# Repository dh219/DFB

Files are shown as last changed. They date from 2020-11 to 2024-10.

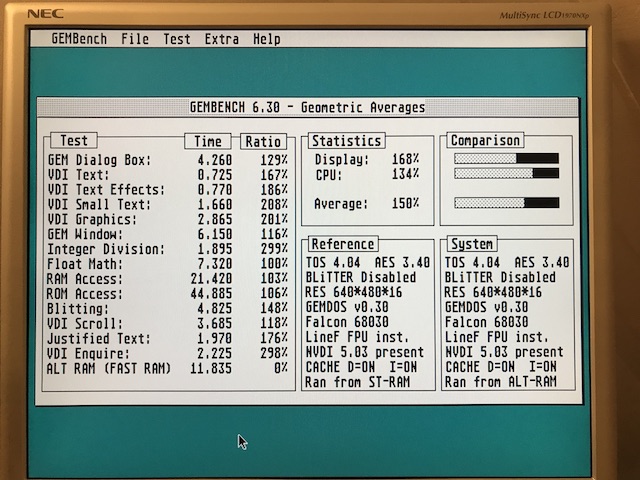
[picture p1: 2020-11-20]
wiki_resources/rev2b_performance.jpeg

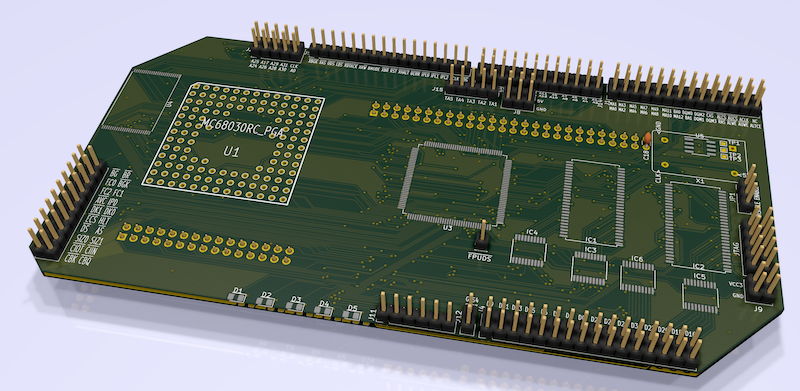
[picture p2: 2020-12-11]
wiki_resources/rev3_kicad.png

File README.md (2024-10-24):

## David's Falcon Booster (DFB)

#### An attempt to build a low-cost memory expansion and accelerator board for the Atari Falcon.

The primary goals of the project are to:

* Be a plug-in board requiring no soldering on the Falcon;
* Increase available RAM beyond the 14MB the stock Falcon can be expanded to;
* Be low cost;
* Provide some acceleration;
* Allow the PSU to remain in the case;
* Be open source.

Some development narration on this project is provided in the [Wiki](https://github.com/dh219/DFB/wiki).

Firmware source (ISE), board design files (KiCAD) and any source for support programs are published at each release.

#### Capabilities

As of 2024 the published firmware supports 64 (2x32) or 128 (2x64) MB of TT-RAM.

It supports only a PGA128 MC68030. The board has been tested between 32 and 50MHz with the CPU normally being the limiting factor.

The FPU is optional and can be run at half the CPU speed, or with an independent oscillator. This is configured by a resistor placement choice.

The Falcon's on-board FPU, if fitted, should be removed to prevent bus conflicts.

---

*Copyright 2020-24 D Henderson, released under GPL2.0*

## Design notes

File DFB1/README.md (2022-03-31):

## David's Falcon Booster Mark 1 (DFB1)

#### Hardware

The directory *kicad5* contains all the Kicad 5 project files and libraries necessary to order or edit the DFB1 PCB.

Kicad is an open source EDA suite. https://www.kicad.org/

Premade gerber files may be found in the releases.

#### Firmware

##### Building

The directory *ise* contains the project files, verilog source and hardware definition files needed to build the firmware for the CPLD.

AMD/Xilinx's ISE Design Suite is required to edit and synthesise the CPLD firmware. Tested with ISE Webpack v14.7.

https://www.xilinx.com/products/design-tools/ise-design-suite/ise-webpack.html

Precompiled (JEDEC) firmwares may be found in the releases.

##### Flashing

Flashing the CPLD can be achieved with the free and open source xc3sprog tool and a Xilinx programmer, or a Raspberry Pi.

http://xc3sprog.sourceforge.net/

https://linuxjedi.co.uk/2021/11/25/revisiting-xilinx-jtag-programming-from-a-raspberry-pi/

#### Assembling

Pick and place positioning files and automated bill of materials file are not yet available, but when they are the board house may be able to partially assemble boards for you.

In the meantime, and for hobbiests, a hand assembly video guide is available on my YouTube channel:

https://www.youtube.com/playlist?list=PLZBirr2xVnY4OkgEWdXNjq90gBGzXah9X

#### Software

I recommend Anders Granlund's TFTools suite to enable the TT-RAM on the DFB1 board. FASTRAM.PRG detects and activates the TT-RAM. MAPROM.PRG will additionally copy TOS to TT-RAM for even better performance but may require a cold boot to work completely correctly. BLITFIX.PRG does not, unfortunately, work with the Falcon.

https://github.com/agranlund/tftools

NVDI is recommended to use the stock TOS4 desktop with TT-RAM enabled as there is no way of disabling the Blitter in TOS4 and unfortunately the Blitter is not compatible with TT-RAM. NVDI replaces the VDI calls that use the Blitter.

An excellent alternative to all the above is EmuTOS, but sadly, as of version 1.1.1, it does not support the Falcon's 16-bit true colour mode.

https://emutos.sourceforge.io/

---

*Copyright 2020-21 D Henderson, released under GPL2.0*

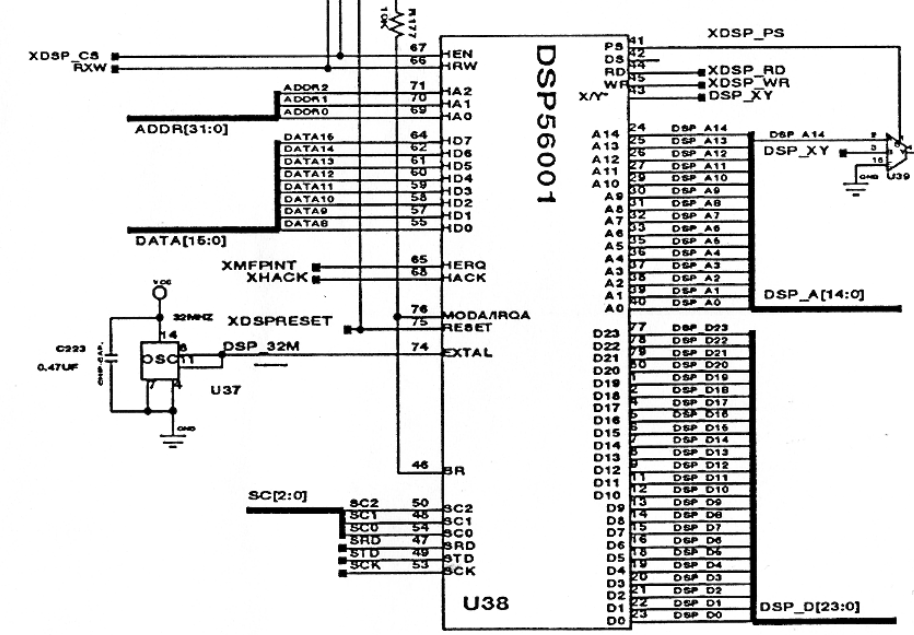
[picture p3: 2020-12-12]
wiki_resources/DSP_schematic.png

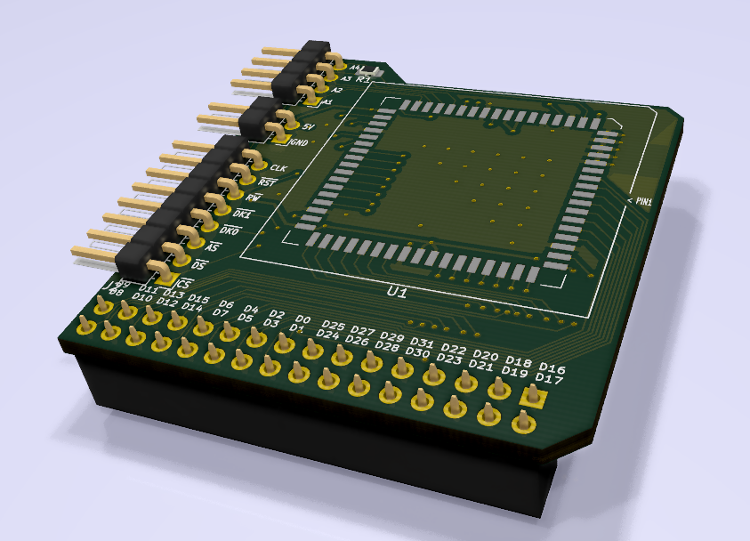
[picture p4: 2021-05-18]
wiki_resources/FPU_hat_render.png

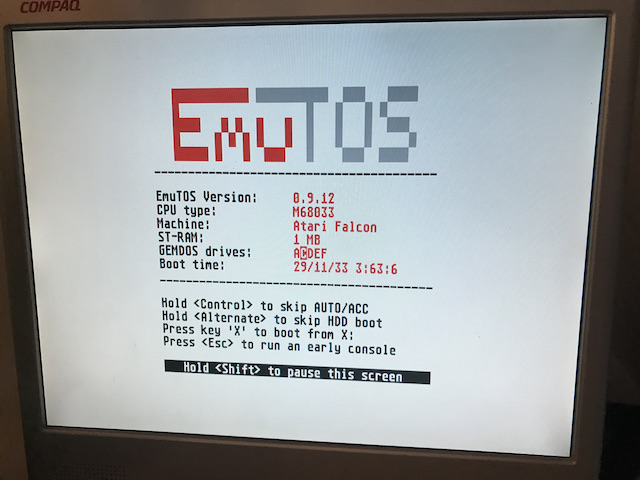
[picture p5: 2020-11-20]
wiki_resources/etos_odd_behaviour.jpeg

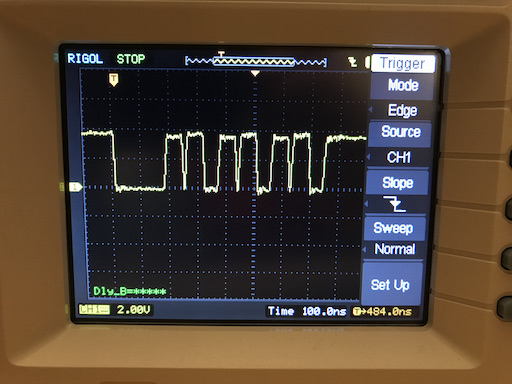
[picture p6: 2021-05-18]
wiki_resources/DSACK0_DFB_timing.jpeg

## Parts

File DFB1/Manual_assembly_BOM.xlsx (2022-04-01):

Assembly Order | Designator | Package | Quantity | Designation | Mouser part | Farnell part | LCSC part | RS part | Approx indiv cost (GBP ex VAT) | Approx line cost | Approximate overall component cost (GBP)
1 | U4 | TQFP-144_20x20mm_P0.5mm | 1 | XC95288XL-10TQG144I |  | 2907289 |  |  | 22 | 22 | NO VAT
1 | C25,C24,C11,C9,C8,C23,C17,C16,C15,C14,C13,C12,C20,C18,C2,C7,C6,C4 | C_0805_2012Metric_Pad1.18x1.45mm_HandSolder | 18 | 100n | Jellybean |  |  |  | 0.03 | 0.54 | 63.04
1 | C22,C10,C19,C1,C3 | C_0805_2012Metric_Pad1.18x1.45mm_HandSolder | 5 | 10u | Jellybean |  |  |  | 0.03 | 0.15
1 | C5 | C_0805_2012Metric_Pad1.18x1.45mm_HandSolder | 1 | 330p | Jellybean |  |  |  | 0.03 | 0.03 | +VAT
1 | R3,R2 | R_0805_2012Metric_Pad1.20x1.40mm_HandSolder | 2 | 2k2 | Jellybean |  |  |  | 0.03 | 0.06 | 75.648
1 | R18,R1,R20,R19,R16 | R_0805_2012Metric_Pad1.20x1.40mm_HandSolder | 5 | 33R NOMINAL | Jellybean |  |  |  | 0.03 | 0.15
1 | RN7,RN6,RN5,RN4,RN2,RN1 | R_Array_Convex_4x0603 | 6 | 10K 1206 |  | 3550050 |  |  | 0.04 | 0.24
1 | R12 | R_0805_2012Metric_Pad1.20x1.40mm_HandSolder | 1 | 4k7 OPTION | Jellybean |  |  |  | 0.03 | 0.03
1 | U1 | SOT-223 | 1 | LM1117-3.3 |  | 3588827 |  |  | 0.65 | 0.65
1 | J9 | PinHeader_1x06_P2.54mm_Vertical | 1 | Conn_01x06_Male | Jellybean |  |  |  | 0.06 | 0.06
TEST JTAG AND PROGRAM |  |  |  |  |  |  |  |  |  | 0
 |  |  |  |  |  |  |  |  |  | 0
2 | X1 | Oscillator_DIP-14-DUAL | 1 | 5V DIP 8 or DIP14 |  | 2508732 |  |  | 3.1 | 3.1
2 | J3 | PinSocket_2x15_P2.54mm_Vertical | 1 | Conn_01x30 |  | 2847247 |  |  | 0.81 | 0.81
2 | J1 | PinSocket_2x25_P2.54mm_Vertical | 1 | Conn_01x50 |  | 2847249 |  |  | 1.35 | 1.35
2 | U2 | MC68030RC_PGA | 1 | MC68030RC_PGA | See Exxos store |  |  |  | 8 | 8
2 | J2 | PinHeader_2x04_P2.54mm_Vertical | 1 | Conn_02x04_Odd_Even | Jellybean |  |  |  | 0.08 | 0.08
TEST IN FALCON SHOULD NOW ACCELERATE |  |  |  |  |  |  |  |  |  | 0
 |  |  |  |  |  |  |  |  |  | 0
3 | IC6,IC5,IC4,IC3 | TSSOP-20_4.4x6.5mm_P0.65mm | 4 | SN74CB3T3245PW |  | 3120942 |  |  | 2.1 | 8.4
3 | IC2,IC1 | TSOP-II-54_22.2x10.16mm_P0.8mm | 2 | IS42S16160G-7TLI |  | 2253829 |  |  | 3.9 | 7.8
TEST IN FALCON SHOULD NOW DETECT TTRAM AND PASS YAARTTT |  |  |  |  |  |  |  |  |  | 0
 |  |  |  |  |  |  |  |  |  | 0
ENTIRELY OPTIONAL TO TASTE |  |  |  |  |  |  |  |  |  | 0
4 | D5,D4,D3,D2,D1 | LED_0805_2012Metric_Pad1.15x1.40mm_HandSolder | 5 | LED SMD 0805 |  | 1581242 |  |  | 0.12 | 0.6
4 | R10,R9,R8,R7,R6 | R_0805_2012Metric_Pad1.20x1.40mm_HandSolder | 5 | 1k | Jellybean |  |  |  | 0.03 | 0.15
 |  |  |  |  |  |  |  |  |  | 0
4 | U3 | PLCC-68_THT-Socket | 1 | MC68882 |  | 1183031 |  |  | 2.15 | 2.15
 |  |  |  |  |  |  |  |  |  | 0
DEBUG/EXPANSION |  |  |  |  |  |  |  |  |  | 0
X | J6 | PinHeader_1x02_P2.54mm_Vertical | 1 | Conn_01x02_Male | Jellybean |  |  |  | 0.02 | 0.02
X | JP1 | PinHeader_1x02_P2.54mm_Vertical | 1 | Conn_01x02_Male | Jellybean |  |  |  | 0.02 | 0.02
X | J5 | PinHeader_2x02_P2.54mm_Vertical | 1 | Conn_02x02_Odd_Even | Jellybean |  |  |  | 0.04 | 0.04
X | J8,J4 | PinHeader_2x03_P2.54mm_Vertical | 2 | Conn_02x03_Odd_Even | Jellybean |  |  |  | 0.06 | 0.12
NOT YET TESTED |  |  |  |  |  |  |  |  |  | 0
E | U5 | TSOP-I-48_18.4x12mm_P0.5mm | 1 | 5V 29F800C-TSOP-48 |  |  |  | 914-2768 | 3.3 | 3.3
 |  |  |  |  |  |  |  |  |  | 0
ONLY FIT IF STABILITY REQUIRES (TEST EACH ONE) |  |  |  |  |  |  |  |  |  | 0
D | R15,R14,R13 | R_0805_2012Metric_Pad1.20x1.40mm_HandSolder | 3 | 10k OPTION | Jellybean |  |  |  | 0.03 | 0.09
 |  |  |  |  |  |  |  |  |  | 0
DO NOT FIT IF R18 POPULATED |  |  |  |  |  |  |  |  |  | 0
O | X2 | Oscillator_DIP-14-DUAL | 1 | 5V DIP 8 or DIP14 |  |  |  |  | 3.1 | 3.1

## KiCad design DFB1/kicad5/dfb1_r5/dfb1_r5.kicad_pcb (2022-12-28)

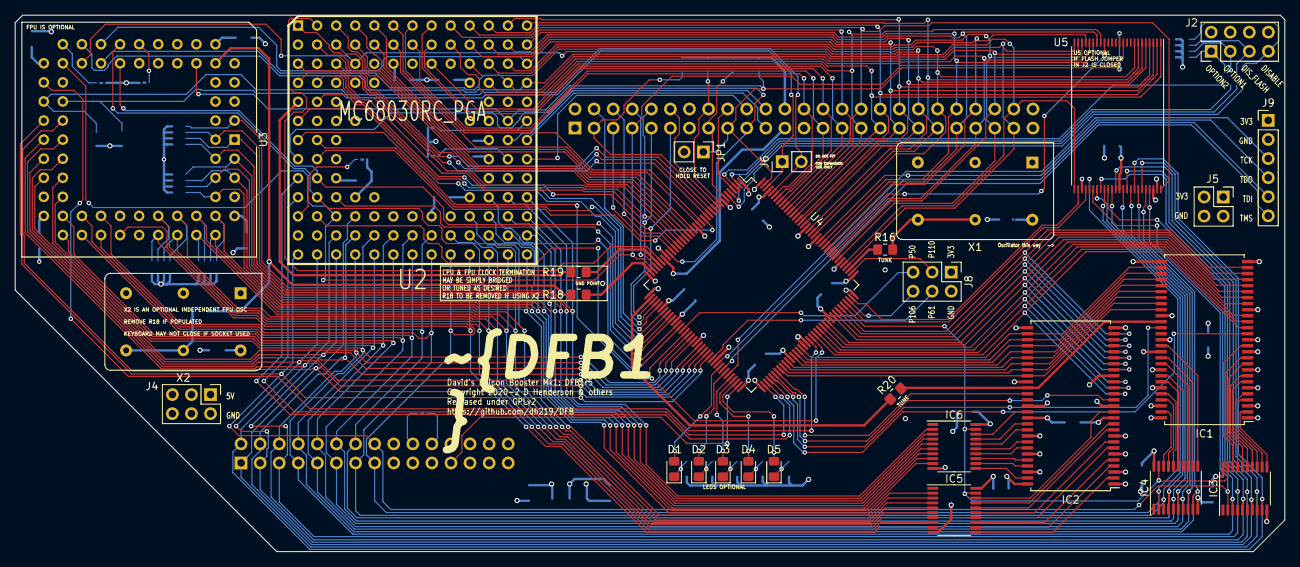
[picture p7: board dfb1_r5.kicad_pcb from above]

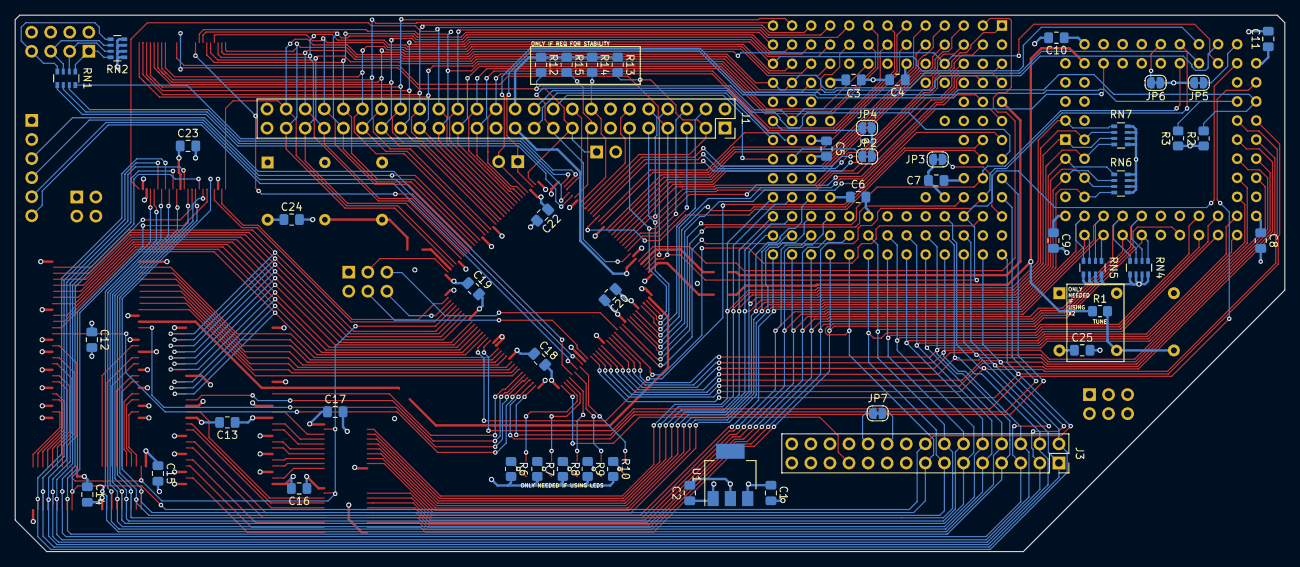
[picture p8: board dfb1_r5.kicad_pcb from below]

Board: 4 copper layers, 169.0 x 71.4 mm, 79 parts (51 on the bottom side), 204 nets.

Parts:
C1, C3, C10, C19, C22: 10u; C_0805_2012Metric_Pad1.18x1.45mm_HandSolder
C2, C4, C6, C7, C8, C9, C11, C12, C13, C14, C15, C16, C17, C18, C20, C23, C24, C25: 100n; C_0805_2012Metric_Pad1.18x1.45mm_HandSolder
C5: 330p; C_0805_2012Metric_Pad1.18x1.45mm_HandSolder
D1, D2, D3, D4, D5: LED; LED_0805_2012Metric_Pad1.15x1.40mm_HandSolder
IC1, IC2: IS42S16320D-7TL; TSOP-II-54_22.2x10.16mm_P0.8mm
IC3, IC4, IC5, IC6: SN74CB3T3245PW; TSSOP-20_4.4x6.5mm_P0.65mm
J1: Conn_01x50; PinSocket_2x25_P2.54mm_Vertical
J2: Conn_02x04_Odd_Even; PinHeader_2x04_P2.54mm_Vertical
J3: Conn_01x30; PinSocket_2x15_P2.54mm_Vertical
J4, J8: Conn_02x03_Odd_Even; PinHeader_2x03_P2.54mm_Vertical
J5: Conn_02x02_Odd_Even; PinHeader_2x02_P2.54mm_Vertical
J6: Conn_01x02_Female; PinHeader_1x02_P2.54mm_Vertical
J9: Conn_01x06_Male; PinHeader_1x06_P2.54mm_Vertical
JP1: Jumper_NO_Small; PinHeader_1x02_P2.54mm_Vertical
JP2, JP3, JP4, JP5, JP6, JP7: Jumper_NC_Small; SolderJumper-2_P1.3mm_Bridged_RoundedPad1.0x1.5mm_DAVID
R1, R16, R18, R19, R20: 33R NOMINAL; R_0805_2012Metric_Pad1.20x1.40mm_HandSolder
R2, R3: 2k2; R_0805_2012Metric_Pad1.20x1.40mm_HandSolder
R6, R7, R8, R9, R10: 1k; R_0805_2012Metric_Pad1.20x1.40mm_HandSolder
R12: 4k7 OPTION; R_0805_2012Metric_Pad1.20x1.40mm_HandSolder
R13, R14, R15: 10k OPTION; R_0805_2012Metric_Pad1.20x1.40mm_HandSolder
RN1, RN2, RN4, RN5, RN6, RN7: 10K; R_Array_Convex_4x0603
U1: LM1117-3.3; SOT-223
U2: MC68030RC_PGA
U3: MC68882; PLCC-68_THT-Socket
U4: XC95288XL-10TQG144I; TQFP-144_20x20mm_P0.5mm
U5: 29F800C-TSOP-48; TSOP-I-48_18.4x12mm_P0.5mm
X1, X2: CXO_DIP14_DIP8_DUAL; Oscillator_DIP-14-DUAL

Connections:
/68030/CDIS: JP2.1, U2.H12
/68030/CIIN: JP3.1, U2.L1
/68030/FPUSIZE: JP6.1, U3.18
/68030/FPU_A0: JP5.1, U3.26
/68030/MMUDIS: JP4.1, U2.F13
/CPLD/LED1: D1.2, U4.64
/CPLD/LED2: D2.2, U4.66
/CPLD/LED3: D3.2, U4.68
/CPLD/LED4: D4.2, U4.69
/CPLD/LED5: D5.2, U4.70
/CPLD/P50: J8.5, U4.50
/CPLD/P61: J8.4, U4.61
/CPLD/P106: J8.6, U4.106
/CPLD/P110: J8.3, U4.110
/CPLD/TCK: J9.3, U4.67
/CPLD/TDI: J9.5, U4.63
/CPLD/TDO: J9.4, U4.122
/CPLD/TMS: J9.6, U4.65
/CPUBGI: J3.22, JP7.2
/CPUBGO: J3.20, JP7.1
/ENABLE_J: J2.7, RN1.4, RN2.5
/EN_ALTRAM_J: J2.3, RN1.2, RN2.7
/EN_FLASH_J: J2.5, RN1.3, RN2.6
/OPTION_J: J2.1, RN1.1, RN2.8
A0: U2.A2, U4.31
A1: J1.48, U2.C4, U3.25, U4.113, U5.25
A2: J1.47, U2.D13, U3.24, U4.112, U5.24
A3: J1.46, U2.D12, U3.23, U4.116, U5.23
A4: J1.45, U2.C13, U3.22, U4.115, U5.22
A5: J1.44, U2.C12, U4.119, U5.21
A6: J1.43, U2.D11, U4.117, U5.20
A7: J1.42, U2.B13, U4.121, U5.19
A8: J1.41, U2.B12, U4.120, U5.18
A9: J1.40, U2.C11, U4.124, U5.8
A10: J1.39, U2.A13, U4.125, U5.7
A11: J1.38, U2.C10, U4.126, U5.6
A12: J1.37, U2.B11, U4.128, U5.5
A13: J1.36, U2.A12, U4.129, U5.4
A14: J1.35, U2.B10, U4.130, U5.3
A15: J1.34, U2.A11, U4.131, U5.2
A16: J1.33, U2.B9, U4.132, U5.1
A17: J1.32, U2.A10, U4.134, U5.48
A18: J1.31, U2.C8, U4.133, U5.17
A19: J1.30, U2.A9, U4.135
A20: J1.29, U2.B8, U4.136
A21: J1.28, U2.A8, U4.137
A22: J1.27, U2.B7, U4.138
A23: J1.26, U2.A7, U4.139
A24: U2.A6, U4.16
A25: U2.B6, U4.17
A26: U2.A5, U4.19
A27: U2.B5, U4.20
A28: U2.A4, U4.21
A29: U2.B4, U4.22
A30: U2.A3, U4.23
A31: U2.B3, U4.24
BA0: IC1.20, IC2.20, U4.96
BA1: IC1.21, IC2.21, U4.97
BMODE: J1.12, U4.10
CLKOSC: R16.1, U4.111
CPUCLK: R19.2, U2.E1
D0: IC6.2, RN7.1, U2.K13, U3.3
D1: IC6.3, RN7.2, U2.K12, U3.2
D2: IC6.4, RN7.3, U2.L13, U3.1
D3: IC6.6, RN7.4, U2.M13, U3.68
D4: IC6.5, RN6.1, U2.L12, U3.67
D5: IC6.7, RN6.3, U2.K11, U3.66
D6: IC6.8, RN6.2, U2.M12, U3.65
D7: IC6.9, RN6.4, U2.L11, U3.64
D8: IC5.2, RN5.4, U2.N13, U3.62
D9: IC5.3, RN5.3, U2.M11, U3.60
D10: IC5.4, RN5.2, U2.L10, U3.59
D11: IC5.5, RN5.1, U2.N12, U3.58
D12: IC5.6, RN4.4, U2.M10, U3.57
D13: IC5.7, RN4.3, U2.N11, U3.56
D14: IC5.8, RN4.2, U2.M9, U3.55
D15: IC5.9, RN4.1, U2.N10, U3.54
D16: IC4.2, J3.15, U2.N9, U3.50, U5.29
D17: IC4.4, J3.14, U2.M8, U3.49, U5.31
D18: IC4.3, J3.13, U2.N8, U3.48, U5.33
D19: IC4.5, J3.12, U2.N7, U3.47, U5.35
D20: IC4.6, J3.11, U2.M7, U3.46, U5.38
D21: IC4.7, J3.10, U2.N6, U3.45, U5.40
D22: IC4.8, J3.9, U2.M6, U3.44, U5.42
D23: IC4.9, J3.8, U2.N5, U3.42, U5.44
D24: IC3.3, J3.7, U2.M5, U3.40, U4.52, U5.30
D25: IC3.5, J3.6, U2.N4, U3.39, U4.53, U5.32
D26: IC3.4, J3.5, U2.N3, U3.38, U4.54, U5.34
D27: IC3.7, J3.4, U2.M4, U3.37, U4.56, U5.36
D28: IC3.6, J3.3, U2.N2, U3.36, U4.57, U5.39
D29: IC3.9, J3.2, U2.M3, U3.35, U4.58, U5.41
D30: IC3.8, J3.1, U2.L4, U3.34, U4.59, U5.43
D31: IC3.2, J3.16, U2.N1, U3.33, U4.60, U5.45
DQM0: IC1.15, U4.76
DQM1: IC1.39, U4.77
DQM2: IC2.15, U4.78
DQM3: IC2.39, U4.79
ENABLE: RN1.5, U4.6
EN_ALTRAM: RN1.7, U4.2
EN_FLASH: RN1.6, U4.5
FC0: J1.11, U2.D2, U4.39
FC1: J1.10, U2.C1, U4.25
FC2: J1.9, U2.D1, U4.40
FPUCLK: R1.1, R18.2, U3.11
GND: C1.2, C2.2, C3.2, C4.2, C5.2, C6.2, C7.2, C8.2, C9.2, C10.2, C11.2, C12.2, C13.2, C14.2, C15.2, C16.2, C17.2, C18.2, C19.2, C20.2, C22.2, C23.2, C24.2, C25.2, IC1.6, IC1.12, IC1.19, IC1.28, IC1.41, IC1.46, IC1.52, IC1.54, IC2.6, IC2.12, IC2.19, IC2.28, IC2.41, IC2.46, IC2.52, IC2.54, IC3.10, IC4.10, IC5.10, IC6.10, J1.1, J1.2, J2.2, J2.4, J2.6, J2.8, J3.17, J3.18, J3.19, J4.2, J4.4, J4.6, J5.2, J5.4, J8.2, J9.2, JP1.2, R6.2, R7.2, R8.2, R9.2, R10.2, U1.1, U2.C5, U2.C7, U2.C9, U2.E3, U2.E11, U2.F3, U2.G3, U2.G11, U2.J3, U2.J11, U2.L5, U2.L7, U2.L8, U2.L9, U3.5, U3.6, U3.7, U3.8, U3.9, U3.12, U3.14, U3.19, U3.30, U3.41, U3.51, U3.63, U4.18, U4.29, U4.36, U4.47, U4.62, U4.72, U4.89, U4.90, U4.99, U4.108, U4.114, U4.123, U4.144, U5.27, U5.46, X1.4, X1.7, X2.4, X2.7
KHZ500: J3.23, U4.71
MA0: IC1.23, IC2.23, U4.100
MA1: IC1.24, IC2.24, U4.101
MA2: IC1.25, IC2.25, U4.102
MA3: IC1.26, IC2.26, U4.103
MA4: IC1.29, IC2.29, U4.88
MA5: IC1.30, IC2.30, U4.87
MA6: IC1.31, IC2.31, U4.86
MA7: IC1.32, IC2.32, U4.85
MA8: IC1.33, IC2.33, U4.83
MA9: IC1.34, IC2.34, U4.82
MA10: IC1.22, IC2.22, U4.98
MA11: IC1.35, IC2.35, U4.81
MA12: IC1.36, IC2.36, U4.80
MD0: IC2.2, IC5.11
MD1: IC2.4, IC5.12
MD2: IC2.5, IC5.13
MD3: IC2.7, IC5.14
MD4: IC2.8, IC5.15
MD5: IC2.10, IC5.16
MD6: IC2.11, IC5.17
MD7: IC2.13, IC5.18
MD8: IC2.42, IC6.18
MD9: IC2.44, IC6.17
MD10: IC2.45, IC6.16
MD11: IC2.47, IC6.15
MD12: IC2.48, IC6.14
MD13: IC2.50, IC6.13
MD14: IC2.51, IC6.12
MD15: IC2.53, IC6.11
MD16: IC1.2, IC3.11
MD17: IC1.4, IC3.12
MD18: IC1.5, IC3.13
MD19: IC1.7, IC3.14
MD20: IC1.8, IC3.15
MD21: IC1.10, IC3.16
MD22: IC1.11, IC3.17
MD23: IC1.13, IC3.18
MD24: IC1.42, IC4.11
MD25: IC1.44, IC4.12
MD26: IC1.45, IC4.13
MD27: IC1.47, IC4.14
MD28: IC1.48, IC4.15
MD29: IC1.50, IC4.16
MD30: IC1.51, IC4.17
MD31: IC1.53, IC4.18
unnamed: D1.1, R10.1
unnamed: D2.1, R9.1
unnamed: D3.1, R8.1
unnamed: D4.1, R7.1
unnamed: D5.1, R6.1
unnamed: R1.2, X2.8, X2.11
unnamed: R16.2, X1.8, X1.11
unnamed: R18.1, U4.35
unnamed: R19.1, U4.32
unnamed: R20.1, U4.38
OPTION: RN1.8, U4.3
RAMCLK: IC1.38, IC2.38, R20.2
ROM_A19: U4.118, U5.16
SIZ0: U2.L2, U4.51
SIZ1: U2.K3, U4.48
VCC: C1.1, C3.1, C4.1, C5.1, C6.1, C7.1, C8.1, C9.1, C10.1, C11.1, C23.1, C24.1, C25.1, J1.24, J1.25, J3.28, J3.29, J3.30, J4.1, J4.3, J4.5, JP2.2, JP3.2, JP4.2, JP5.2, JP6.2, R2.1, R3.1, R12.1, R13.1, R14.1, R15.1, RN4.5, RN4.6, RN4.7, RN4.8, RN5.5, RN5.6, RN5.7, RN5.8, RN6.5, RN6.6, RN6.7, RN6.8, RN7.5, RN7.6, RN7.7, RN7.8, U1.3, U2.C6, U2.D4, U2.D10, U2.F2, U2.F11, U2.H3, U2.H11, U2.K4, U2.K10, U2.L6, U3.10, U3.16, U3.17, U3.27, U3.43, U3.52, U3.53, U3.61, U5.37, U5.47, X1.14, X2.14
VCC3: C2.1, C12.1, C13.1, C14.1, C15.1, C16.1, C17.1, C18.1, C19.1, C20.1, C22.1, IC1.1, IC1.3, IC1.9, IC1.14, IC1.27, IC1.37, IC1.43, IC1.49, IC2.1, IC2.3, IC2.9, IC2.14, IC2.27, IC2.37, IC2.43, IC2.49, IC3.20, IC4.20, IC5.20, IC6.20, J5.1, J5.3, J8.1, J9.1, RN2.1, RN2.2, RN2.3, RN2.4, U1.2, U4.1, U4.8, U4.37, U4.42, U4.55, U4.73, U4.84, U4.109, U4.127, U4.141
XCPUCLK: J1.23, U4.30
XR~W: J1.7, U2.L3, U3.28, U4.34, U5.11
~AS: U2.J2, U3.21, U4.46
~AVEC: U2.E2, U4.43
~BERR: J1.19, U2.H1, U4.28
~BG: U2.B2, U4.12
~BGK: U2.C3, U4.14
~BOE: IC3.19, IC4.19, IC5.19, IC6.19, U4.104
~BR: U2.A1, U4.13
~CAS: IC1.17, IC2.17, U4.94
~CBACK: U2.J1, U4.75
~CBREQ: U2.K1, U4.74
~DS: U2.K2, U3.20, U4.49
~DSACK0: U2.F1, U4.45
~DSACK1: U2.G2, U4.44
~FPUCS: U3.29, U4.91
~FPUDSACK0: J6.2, R2.2, U3.31, U4.140
~FPUDSACK1: J6.1, R3.2, U3.32, U4.142
~HLT: U2.H2, U4.15
~IPL0: J1.20, U2.H13
~IPL1: J1.21, U2.G13
~IPL2: J1.22, U2.G12
~LDS: J1.5, U4.27
~RAMWE: IC1.16, IC2.16, U4.93
~RAS: IC1.18, IC2.18, U4.95
~ROMCE: U4.107, U5.26
~ROMOE: U4.105, U5.28
~RST: J1.17, JP1.1, R12.2, U2.F12, U3.13, U4.143, U5.12
~STERM: U2.G1, U4.92
~UDS: J1.6, U4.26
~XAS: J1.4, U4.41
~XBG: J1.15, R15.2, U4.7
~XBGK: J1.3, R13.2, U4.11
~XBR: J1.16, R14.2, U4.9
~XDTACK: J1.8, U4.33
~XHALT: J1.18, U4.4

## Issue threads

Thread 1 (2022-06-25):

Footprint Tweak

DominoTree, 2022-06-25:
Thank you for the time and effort you've put in to developing something amazing!

I built Gerbers and placed an order for some boards (with PCBWay) and they informed me that the pad-to-pad clearance for the FPGA was 0.02mm below their minimum tolerance for any soldermask color other than green. After checking the Xilinx spec sheet at https://www.xilinx.com/support/documents/package_specs/tq144.pdf it looks like the maximum pin width is 0.27mm, whereas the default KiCad package is 0.30mm.

I made a new package based with 0.27mm pins tweaked the wider track widths connecting to it, as well as made sure the smaller tracks were centered in the pads, and then built new Gerbers and submitted them. Hopefully they pass PCBWay's DRC with those changes. I'll post an update here if so or if I end up needing to do more.

My changes are at https://github.com/DominoTree/DFB if you'd like to swap footprints or anything. I used KiCad 6 and just modified the footprint on the PCB itself - if you want to use it and have trouble let me know and I'll re-generate it in KiCad 5 and save it as its own footprint. This could be a quick way to make these boards easier and cheaper for more folks to have manufactured.

Thanks again, and feel free to let me know if you have any questions or if there's anything I can help with!
Nick

dh219, 2022-07-29:
Hi there.

I'm not ignoring this, but I've not yet decided on what the best course of action is. I'm unsure that changing the pad widths to be exactly the pin widths is a good idea. Currently I'm leaning towards leaving it as it is, as you've provided an alternative already and there is an option at PCBWay, just in the stock colour. I'll continue to mull this over and perhaps seek advice.

Cheers.

DominoTree, 2022-07-30:
No worries - it's certainly nothing critical and it's an issue I'd never
even considered until I ran into it! Makes me curious to find out
whether other fabs doing purple soldermask have similar color-specific
tolerance requirements.

I don't recall coming across an actual design document from Xilinx with
the suggested footprint for the package, but I believe there was still
some "wiggle room" to make the pads slightly larger and still remain
within the fab's requirements, so that might make sense if it works.

The boards and stencil came out great and I just need to get a hold of
some FPGAs to assemble one and confirm it all still works as expected.

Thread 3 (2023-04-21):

Kicad 5 project -- missing custom footprint duplicated from standard footprint

sporniket, 2023-04-21:
Hello,

Working on fixing the portability of the kicad project (see also PR #2 ).

There is a reference to a footprint `Jumper:SolderJumper-2_P1.3mm_Bridged_RoundedPad1.0x1.5mm_DAVID` that seems to me a duplicate from the builtin `Jumper:SolderJumper-2_P1.3mm_Bridged_RoundedPad1.0x1.5mm`, but as it is located in the same system library, it is outside this repository.

What is different in your custom reference ? Is it possible to go back to the standard footprint ? Otherwise, it would be good that you include your custom version into the local footprint library that you made.

dh219, 2023-04-26:
Hi there,

The only difference is that instead of two briding traces that would have to be cut by the intrepid modder, this has only one. It's trivial and it could be swapped back with ease.

Or the jumper could be dropped -- they're their in case switching to 16 bit FPU mode was required after manufacture.

I thought the library ('david') was included, but I'll review this when I get a time. Thanks.

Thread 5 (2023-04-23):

Custom libraries are not referenced in the kicad project

sporniket, 2023-04-23:
When opening the schematics, all the custom symbols are replaced by big squares labelled with "??".

&rArr; either keep the library folder where it is and add the custom symbol libraries into the project, taking care of expressing the pathes relative to the project directory

&rArr; or move the library folder into the kicad project and then add these libraries into the project (in this case Kicad use relative pathes without being told to) &rArr; see PR #2

dh219, 2023-04-26:
Will fold this into [issue 3](https://github.com/dh219/DFB/issues/3)

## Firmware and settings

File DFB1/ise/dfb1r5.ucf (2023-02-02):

NET "A<27>" LOC = "P20" ;
NET "A<28>" LOC = "P21" ;
NET "A<29>" LOC = "P22" ;
NET "A<30>" LOC = "P23" ;
NET "A<31>" LOC = "P24" ;
NET "FC<1>" LOC = "P25" ;
NET "UDS" LOC = "P26" ;
NET "LDS" LOC = "P27" ;

NET "XBR" LOC = "P9" ;
NET "BMODE" LOC = "P10" ;
NET "XBGK" LOC = "P11" ;
NET "BG" LOC = "P12" ;
NET "BR" LOC = "P13" ;
NET "BGK" LOC = "P14" ;
NET "HLT" LOC = "P15" ;
NET "A<24>" LOC = "P16" ;
NET "A<24>" LOC = "P16" ;
NET "A<25>" LOC = "P17" ;
NET "A<26>" LOC = "P19" ;

NET "BERR" LOC = "P28" ;
NET "XCPUCLK" LOC = "P30" ;
NET "A<0>" LOC = "P31" ;
NET "CPUCLK" LOC = "P32" ;
NET "XDTACK" LOC = "P33" ;


NET "OPTION1" LOC = "P2" ;
NET "OPTION2" LOC = "P3" ;
NET "XHALT" LOC = "P4" ;
NET "EN_FLASH" LOC = "P5" ;
NET "ENABLE" LOC = "P6" ;
NET "XBG" LOC = "P7" ;


NET "XRW" LOC = "P34" ;
NET "FPUCLK" LOC = "P35" ;
NET "CLKRAM" LOC = "P38" ;
NET "FC<0>" LOC = "P39" ;
NET "FC<2>" LOC = "P40" ;
NET "XAS" LOC = "P41" ;
NET "AVEC" LOC = "P43" ;
NET "DSACK<1>" LOC = "P44" ;

NET "A<19>" LOC = "P135" ;
NET "A<20>" LOC = "P136" ;
NET "A<21>" LOC = "P137" ;
NET "A<22>" LOC = "P138" ;
NET "A<23>" LOC = "P139" ;
NET "FPUDSACK<0>" LOC = "P140" ;
NET "FPUDSACK<1>" LOC = "P142" ;
NET "RST" LOC = "P143" ;

NET "DSACK<0>" LOC = "P45" ;
NET "AS" LOC = "P46" ;
NET "SIZ<1>" LOC = "P48" ;
NET "DS" LOC = "P49" ;

NET "A<14>" LOC = "P130" ;
NET "A<15>" LOC = "P131" ;
NET "A<16>" LOC = "P132" ;
NET "A<18>" LOC = "P133" ;
NET "A<17>" LOC = "P134" ;

NET "P50" LOC = "P50" ;
NET "SIZ<0>" LOC = "P51" ;
NET "D<0>" LOC = "P52" ;
NET "D<1>" LOC = "P53" ;
NET "D<2>" LOC = "P54" ;
NET "D<3>" LOC = "P56" ;
NET "D<4>" LOC = "P57" ;
NET "D<5>" LOC = "P58" ;
NET "D<6>" LOC = "P59" ;

NET "A<6>" LOC = "P117" ;
NET "ROM_A19" LOC = "P118" ;
NET "A<5>" LOC = "P119" ;
NET "A<8>" LOC = "P120" ;
NET "A<7>" LOC = "P121" ;
NET "A<9>" LOC = "P124" ;
NET "A<10>" LOC = "P125" ;
NET "A<11>" LOC = "P126" ;
NET "A<12>" LOC = "P128" ;
NET "A<13>" LOC = "P129" ;

NET "D<7>" LOC = "P60" ;
NET "P61" LOC = "P61" ;
NET "LED<1>" LOC = "P64" ;
NET "LED<2>" LOC = "P66" ;
NET "LED<3>" LOC = "P68" ;
NET "LED<4>" LOC = "P69" ;
NET "LED<5>" LOC = "P70" ;

NET "P110" LOC = "P110" ;
NET "CLKOSC" LOC = "P111" ;
NET "A<2>" LOC = "P112" ;
NET "A<1>" LOC = "P113" ;
NET "A<4>" LOC = "P115" ;
NET "A<3>" LOC = "P116" ;

NET "KHZ500" LOC = "P71" ;
NET "CBREQ" LOC = "P74" ;
NET "CBACK" LOC = "P75" ;
NET "DQM<0>" LOC = "P76" ;
NET "DQM<1>" LOC = "P77" ;
NET "DQM<2>" LOC = "P78" ;

NET "MA<0>" LOC = "P100" ;
NET "MA<1>" LOC = "P101" ;
NET "MA<2>" LOC = "P102" ;
NET "MA<3>" LOC = "P103" ;
NET "BOE" LOC = "P104" ;
NET "ROMOE" LOC = "P105" ;
NET "P106" LOC = "P106" ;
NET "ROMCE" LOC = "P107" ;

NET "DQM<3>" LOC = "P79" ;
NET "MA<12>" LOC = "P80" ;
NET "MA<11>" LOC = "P81" ;
NET "MA<9>" LOC = "P82" ;
NET "MA<8>" LOC = "P83" ;
NET "MA<7>" LOC = "P85" ;
NET "MA<6>" LOC = "P86" ;
NET "MA<5>" LOC = "P87" ;
NET "MA<4>" LOC = "P88" ;

NET "FPUCS" LOC = "P91" ;
NET "STERM" LOC = "P92" ;
NET "RAMWE" LOC = "P93" ;
NET "CAS" LOC = "P94" ;
NET "RAS" LOC = "P95" ;
NET "BA<0>" LOC = "P96" ;
NET "BA<1>" LOC = "P97" ;
NET "MA<10>" LOC = "P98" ;
#Created by Constraints Editor (xc95288xl-tq144-10) - 2022/11/28
NET "XCPUCLK" TNM_NET = XCPUCLK;
TIMESPEC TS_XCPUCLK = PERIOD "XCPUCLK" 16 MHz HIGH 50%;
NET "KHZ500" TNM_NET = KHZ500;
TIMESPEC TS_KHZ500 = PERIOD "KHZ500" 2 us HIGH 50%;
NET "CLKOSC" TNM_NET = CLKOSC;
TIMESPEC TS_CLKOSC = PERIOD "CLKOSC" 50 MHz HIGH 50%;
#NET "CPUCLK" OFFSET = OUT 20 ns AFTER "CLKOSC";
#NET "FPUCLK" OFFSET = OUT 20 ns AFTER "CLKOSC";
#NET "CLKRAM" OFFSET = OUT 20 ns AFTER "CLKOSC";

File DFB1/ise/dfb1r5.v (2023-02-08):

`timescale 1ns / 1ps

/* DFB1 is Copyright 2019-21 D Henderson.
/* SDRAM controller is based on work Copyright S J Leary 
/* Released under the terms of the GPLv2
/* See LICENCE.TXT
*/

module dfb1r5(

	input [31:0]    	A,
	input [2:0] 	FC,
	inout	BERR,
	input   			XCPUCLK,
	output FPUCLK,
	input OPTION1,
	input OPTION2,
	output XHALT,
	input EN_FLASH,
	input ENABLE,
	input			XBG,
	inout			XBR,
	output BMODE,
	inout			XBGK,
	input				BG,
	output			BR,
	output			BGK,
	output  			HLT,
	input P142,
	input				RST,
	output   		CPUCLK,
	inout XDTACK,
	input XRW,
	output  			CLKRAM,
	output			UDS,
	output			LDS,
	inout				XAS,
	output AVEC,
	inout [1:0] 	DSACK,
	input [1:0] FPUDSACK,
	input				AS,
	input [1:0] 	SIZ,
	input				DS,
	output ROM_A19,
	inout [7:0] D,
	output [1:5] LED,

	output P50,	//CLK
	output P61,	// MOSI
	input P106, // MISO
	output P110, // CS

	input   			CLKOSC,
	input KHZ500,
	input CBREQ,
	output			CBACK,
	output [3:0] 	DQM,
	output [12:0]  MA,
	output FPUCS,
	output			STERM,
	output			RAMWE,
	output			CAS,
	output			RAS,
	output [1:0] 	BA,
	output BOE,
	output ROMOE,
	output ROMCE

);


// EmuTOS doesn't seem to like booting at full speed -- give it time to get started.
reg [20:0] resetcounter = 'd0;
always @( negedge KHZ500) begin
	if( ~RST ) begin
		resetcounter <= 'd0;
	end else begin
		resetcounter <= resetcounter + 'd1;
	end
end

wire speedallowtrigger = resetcounter[20];
wire resetblock; // active low
FDCP latch_resetblock( .D( 1'b1 ), .C( ~speedallowtrigger ), .CLR( ~RST ), .PRE( 1'b0 ), .Q( resetblock ) );

/* config section */
reg [7:0] reg_dfb = 8'b11111101;
reg [7:0] reg_spi = 8'b11111111; // [7] = busy; [6] = read req; [5-2] reserved ; [1] = low speed clock ; [0] = CS

reg [7:0] d_in;
reg [7:0] reg_spi_write_data = 'hFF;
reg [7:0] reg_spi_read_data = 'hFF;

reg spi_xfer = 1'b0; // active high
reg [5:0] spi_xfer_state = 'd0;

reg spi_clk = 1'b0;
reg spi_mosi = 1'b1;

reg DISABLE = 1'b1;
reg DISABLE_FLASH_ROM = 1'b1;
reg DISABLE_ALTRAM = 1'b1;
reg DISABLE_FAST = 1'b1;
always @(posedge RST) begin
	DISABLE <= ENABLE;
	DISABLE_FLASH_ROM <= EN_FLASH;
	DISABLE_FAST <= OPTION2;
//	DISABLE <= reg_dfb[0];
//	DISABLE_FLASH_ROM <= reg_dfb[1];
end
/*
always @(*) begin
	DISABLE_FAST <= reg_dfb[3];
end
*/
wire [1:0] FPUSPEED = reg_dfb[5:4];

wire HIGHZ;

wire [3:0] state;

wire hlt;
/* optimise */
ARBDFB1 arbdfb1 (
	.DISABLED( DISABLE ),
	.CLOCK(~XCPUCLK),
	._RST(RST),
	._XAS(XAS),
	._XBR(XBR),
	._XBG(XBG),
	._XBGK(XBGK),
	._AS(AS),
	._BG(BG),

	._BR(BR),
	._BGK(BGK),
	._HLT(HLT),
	._XHALT(XHALT),
	.HIGHZ(HIGHZ),
	
	.STATE(state)
);

wire fpu = AS | {FC,A[19:16]} != 7'b1110010; // co-processor decode
wire ttram_access = ~DISABLE_ALTRAM | ( A[27:24] == 'hF | A[27:24] == 'h0 );
wire rom_access =  ~DISABLE_FLASH_ROM | A[27:20] != 8'h0E; // Flash ROM
wire dsp_access = A[27:8] != 20'h0FFA2;
wire berr_ram = OPTION1 ? A[26:24] != 3'b101 : A[27:24] != 4'b1001; // 128MB / 64 switch
wire reg_access = A[31:4] != 28'h00F1DFB; // our register F1DFxx


reg flash_access = 1'b1;
always @(negedge XAS ) begin
	flash_access <= ~( ( A[23:20] == 4'hF ) & ( ( A[19:17] == 3'b100 ) | ( { A[19], |A[18:17] } == 2'b01 ) ) ); // F20000-F9FFFF -- F && ( 8/9 || 2-7 )
end


reg CLKOSC_2 = 1'b1;
always @( posedge CLKOSC ) begin
	CLKOSC_2 <= ~CLKOSC_2;
end

// we don't allow switching from slow back to fast for two clock cycles after XDTACK -- this gives full ST ram access speed for negligible TTRAM overhaed
wire [1:0] xdtack_delay;
FDCP ff_xdtack1( .D( XDTACK ), .C( ~XCPUCLK), .CLR( 1'b0 ), .PRE( 1'b0 ), .Q(xdtack_delay[0]) );
FDCP ff_xdtack2( .D( xdtack_delay[0] ), .C( ~XCPUCLK  ), .CLR( 1'b0 ), .PRE( 1'b0 ), .Q(xdtack_delay[1]) );
wire clockholdoff = &xdtack_delay[1:0];
wire lowspeed = DISABLE_FAST & resetblock & fpu & ( AS | ~ttram_access | ~rom_access ) & clockholdoff ; // low active (rom access here too)
//wire lowspeed = DISABLE_FAST & resetblock & ( AS | ~ttram_access | ~rom_access | ~fpu ) & clockholdoff ; // low active (rom access here too)

wire CPUCLK_D;
wire clock_block;

clockmux cm1 ( .clk0( CLKOSC ), 
	.clk1( XCPUCLK  ), 
	.select( lowspeed ),
	.active1( clock_block ),
	.out_clock( CPUCLK_D ) 
);

/* RAM */

sdram SDRAM (
	// inputs
	.RESET(RST),

	.CLKCPU (CPUCLK_D),
	.CLK    (CPUCLK_D),

	.A(A),
	.SIZ(SIZ),

	.AS30(AS),
	.RW30(XRW),
	.DS30(DS),
	.CBREQ(CBREQ),

	// outputs
	.ACCESS(ttram_access),
	.CBACK(CBACK),
	.STERM(STERM),

	.ARAM(MA),
	.BA(BA),

	.CAS(CAS),
	.RAS(RAS),

	.DQM(DQM),

	.RAMWE(RAMWE)
);

/*******/


wire [5:0] AS_DELAY;
FDCP ff_asdly0( .D(AS), .C( ~CPUCLK ), .CLR(1'b0), .PRE( AS ), .Q(AS_DELAY[0]) );          // timings as per 50MHz
FDCP ff_asdly1( .D(AS_DELAY[0]), .C( ~CPUCLK ), .CLR(1'b0), .PRE( AS ), .Q(AS_DELAY[1]) ); // 20ns
FDCP ff_asdly2( .D(AS_DELAY[1]), .C( ~CPUCLK ), .CLR(1'b0), .PRE( AS ), .Q(AS_DELAY[2]) ); // 40ns
FDCP ff_asdly3( .D(AS_DELAY[2]), .C( ~CPUCLK ), .CLR(1'b0), .PRE( AS ), .Q(AS_DELAY[3]) ); // 60ns // this might be being a bit naughty -- change to [4] if unstable
FDCP ff_asdly4( .D(AS_DELAY[3]), .C( ~CPUCLK ), .CLR(1'b0), .PRE( AS ), .Q(AS_DELAY[4]) ); // 80ns
FDCP ff_asdly5( .D(AS_DELAY[4]), .C( ~CPUCLK ), .CLR(1'b0), .PRE( AS ), .Q(AS_DELAY[5]) ); // 100ns


// synthesise flash xdtack
wire [1:0] flash_xas_delay;
FDCP ff_flash_xas_delay1( .D(  XAS | (flash_access&reg_access) ), 				.C( ~XCPUCLK ), .PRE( XAS ), .CLR( 1'b0 ), .Q( flash_xas_delay[0] ) );
FDCP ff_flash_xas_delay2( .D(  flash_xas_delay[0] ), 				.C( ~XCPUCLK ), .PRE( XAS ), .CLR( 1'b0 ), .Q( flash_xas_delay[1] ) );
wire FLASH_DTACK = flash_xas_delay[1];

assign BOE = 1'b0; //ttram_access | AS;


reg AVECCYCLE = 1'b1;
always @(negedge AS) begin
	AVECCYCLE <= ( FC[2:0] != 3'b111 | A[19:16] != 4'b1111 ) | ( A[3:1] != 'd2 && A[3:1] != 'd4 );
end

wire [2:0] oldxdtack;
FDCP ff_xdtackdly1( .D( XDTACK ), .C( XCPUCLK ), .CLR(1'b0), .PRE( 1'b0 ), .Q(oldxdtack[0]) );
FDCP ff_xdtackdly2( .D(oldxdtack[0]), .C( XCPUCLK ), .CLR(1'b0), .PRE( 1'b0 ), .Q(oldxdtack[1]) );
FDCP ff_xdtackdly3( .D(oldxdtack[1]), .C( XCPUCLK ), .CLR(1'b0), .PRE( 1'b0 ), .Q(oldxdtack[2]) );
wire xas_holdoff_dsp = ~dsp_access & ~oldxdtack[1] & XAS;


wire [1:0] RAM_DTACK = { XDTACK | ~dsp_access | ~AVECCYCLE, 1'b1 };
wire [1:0] ROM_DTACK = { rom_access | ( lowspeed ? AS_DELAY[4] : AS_DELAY[1] ), 1'b1 };
wire [1:0] DSP_DTACK = { 1'b1, XDTACK | dsp_access };
wire [1:0] FPU_DSACK_INT = fpu | FPUDSACK;
wire [1:0] REG_DSACK = { AS | reg_access, 1'b1 }; // only really an 8 bit port, but pretend to be 16 to keep compatibility when being read from the Falcon's motherboard in disabled state

/* direct DSACK connections */
/*
wire [1:0] DSACK_INT = ( REG_DSACK & RAM_DTACK & ROM_DTACK & DSP_DTACK & { FLASH_DTACK, 1'b1 } );
assign DSACK = fpu ? DSACK_INT : 2'bzz;
*/

/* DSACK via CPLD */
assign DSACK = ( REG_DSACK & RAM_DTACK & ROM_DTACK & DSP_DTACK & FPU_DSACK_INT & { FLASH_DTACK, 1'b1 } );

// assignments
assign FPUCS = fpu;

wire xas =  AS | xas_holdoff_dsp | ~ttram_access | ~rom_access | ~fpu;
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

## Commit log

2020-11-20 Adding some board revision snaps
2020-11-20 Adding rev3 kicad model
2020-12-12 Adding DSP schematic image
2022-01-15 Initial commit of DFB1r5
    [68030.sch, RAM.sch, ROM.sch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]
2022-03-31 Added a BOM for manual assembly.
    [Manual_assembly_BOM.xlsx]
2022-04-01 Corrected a part number
    [Manual_assembly_BOM.xlsx]
2022-11-16 Added some commented out code to support direct DSACK connections in next board revision
2022-12-28 Jumper labels updated to reflect production gerbers
    [dfb1_r5.kicad_pcb]
2023-01-31 SPI work
2023-02-02 SPI work continues. Removing pointless offset instruction in the UCF
2023-02-08 SPI working with clock switch albeit in a broken way. Need to consolidate duplex mode
    [dfb1r5.v]
2023-02-08 Duplex SPI working.
2023-04-21 fixed : moved kicad custom libraries directory inside kicad project directory and added to project library tables

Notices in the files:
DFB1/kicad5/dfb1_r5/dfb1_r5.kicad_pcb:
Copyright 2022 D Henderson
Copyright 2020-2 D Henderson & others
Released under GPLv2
